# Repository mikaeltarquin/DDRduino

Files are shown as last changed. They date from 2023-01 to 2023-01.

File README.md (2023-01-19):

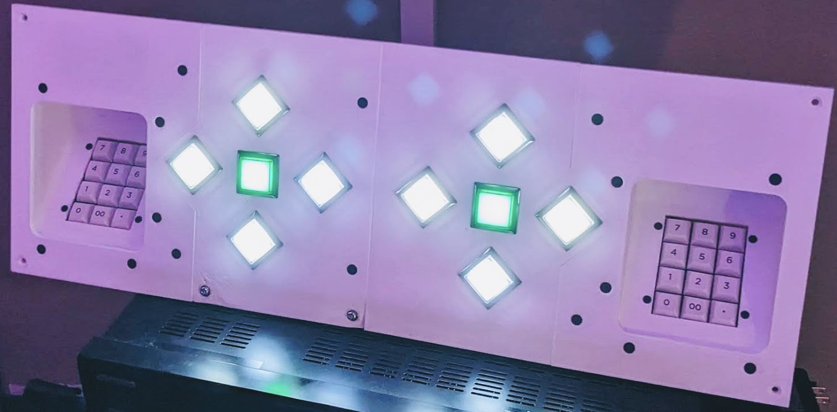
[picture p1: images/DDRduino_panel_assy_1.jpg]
DDRduino Control Panel Build

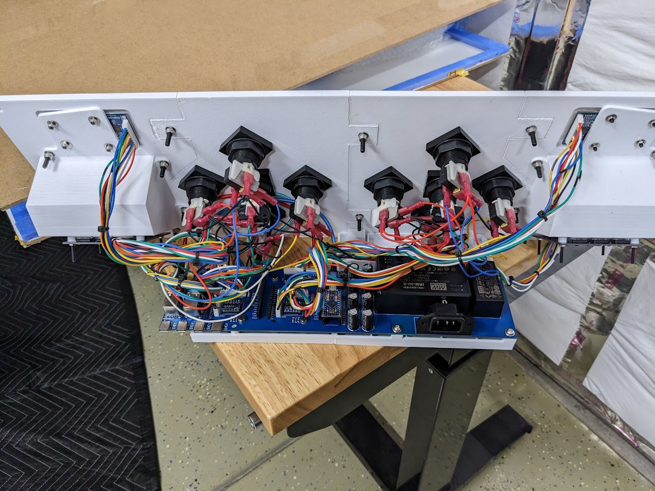
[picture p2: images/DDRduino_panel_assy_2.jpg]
DDRduino Control Panel wiring gore


# DDRduino
Custom PCB for handling DDR control panel, keypad, card reader, and LED controls.
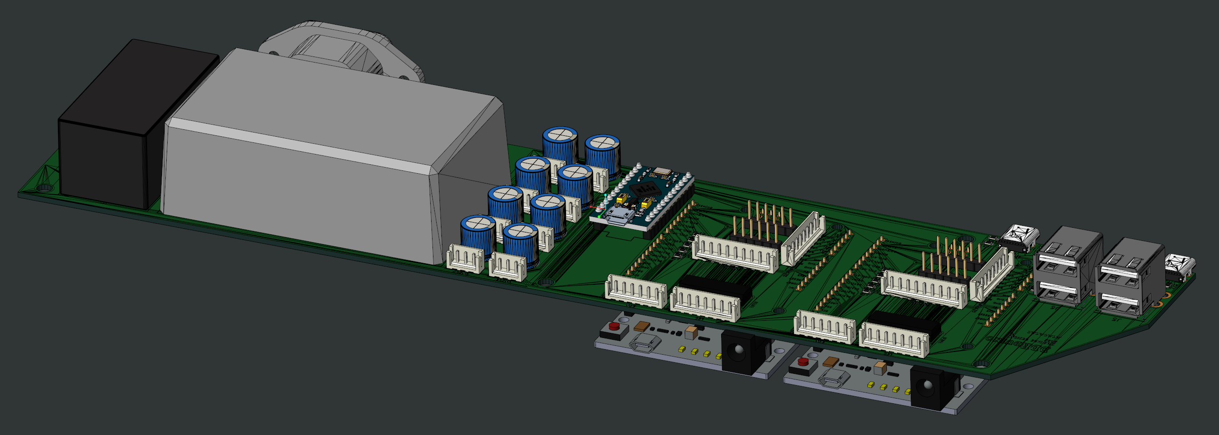
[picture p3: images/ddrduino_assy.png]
DDRduino Assembly


# Keymani
A side project for DDRduino, but theoretically compatible with regular setups as well! This is a 12 button matrix numpad, and connects to the rest of the system with an 8 pin JST connector.
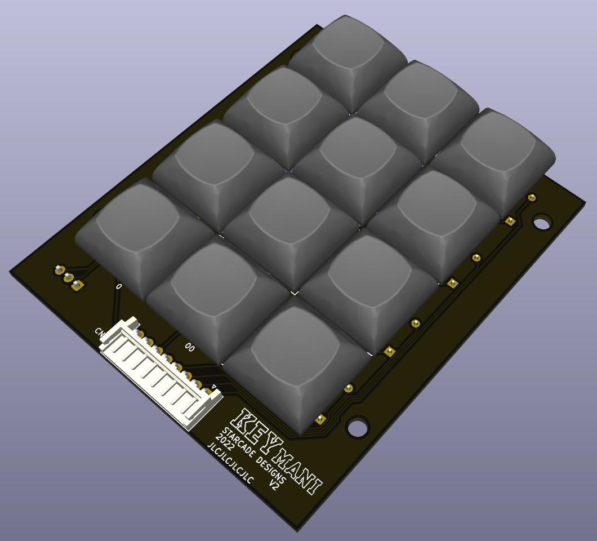
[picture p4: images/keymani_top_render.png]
Keymani PCB


# Acknowledgements
[PN5180-cardio Navigation LPCD](https://github.com/CrazyRedMachine/PN5180-cardio/tree/navigation-lpcd) by CrazyRedMachine 

[WS2812B Addressable LED Arduino Code](https://github.com/Moldypie/hid-lights-with-individually-addressable-strips-and-a-keypad) by Moldypie

# Parts List
## Top Level Components

| Component | Description |
| --- | --- |
| DDRduino Assembly | Integrated board combining microcontrollers, USB interfaces, JST connector headers for Buttons/LEDs/card reader/keypad, and lighting power supplies. |
| Keymani Assembly | A 12-key matrix numpad for entering your PIN. |
| 8x IST 406 White<br><br>2x IST 406 Green | IST-406 White buttons for the direction buttons.<br><br>2x IST-406 Green buttons for the Start buttons.<br><br>[IST MALL link](https://www.istmall.co.kr/us/goods/goods_view.php?goodsNo=1009992263) | 
| 2x PN5180 | NFC card readers to read your IC cards.<br><br>[AliExpress link](https://www.aliexpress.com/w/wholesale-pn5180.html) |
| Control Panel | Up to you! I designed a very janky panel that I've been printing in pieces, you can do better! |

## DDRduino Components

| Component ID | Component | Description |Quantity |
| --- | --- | --- | --- |
| U1 | 703W-00/54 | AC Power Entry Module | 1 |
| U101, U201 | TBD62003APG | Transistor Array | 2 |
| U301 | Arduino ProMicro | microcontroller for cab LEDs | 1 |
| <> | Arduino Leonardo | microcontroller for controls/button LEDs/card reader/keypad | 2 |
| <> | BOB-12009 | SparkFun Logic Level Converter - Bi-Directional | 2 |
| PS1 | IRM-60-5 PSU | power supply for cab LEDs | 1 |
| PS2 | IRM-20-12 PSU | power supply for button LEDs | 1 |
| C301-C308 | 1000 uF D10.0mm | Radial electrolytic capacitors (I used 25V) | 8 |
| R1-R4, R13-R14 | 1 MOhm 0805 | SMD resistors | 6 |
| R5-R12 | 5.11 kOhm 0805 | SMD resistors | 8 |
| R101-R105, R201-R205 | 10 kOhm 0805 | SMD resistors | 10 |
| R301-R308 | 330 Ohm 0805 | SMD resistors | 8 |
| J5-J6 | USB1035-GF-P-0-B-B	| USB-A ports | 2 |
| J1-J4 | USB4085-GF-A | USB-C ports | 4 |
| CN101, CN201 | JST_EH_B6B-EH-A_1x06_P2.50mm_Vertical	| 6 pin connector header for buttons | 2 |
| CN102, CN202 | JST_EH_B7B-EH-A_1x07_P2.50mm_Vertical	| 7 pin connector header for button LEDs | 2 |
| CN104, CN204 | JST_EH_B11B-EH-A_1x11_P2.50mm_Vertical	| 11 pin connector header for PN5180 card reader | 2 |
| CN105, CN205 | JST_EH_B8B-EH-A_1x08_P2.50mm_Vertical	| 8 pin connector header for keypad | 2 |
| CN301-CN308 | JST_EH_B3B-EH-A_1x03_P2.50mm_Vertical	| 3 pin connector header for cab LEDs | 8 |
| CN111-CN112, CN211-CN212, J101, J201 | PinHeader_1x06_P2.54mm_Vertical	| 6 pin header for logic level converter, Leonardo | 6 |
| J102-J103, J202-J203 | PinHeader_1x08_P2.54mm_Vertical	| 8 pin header for Leonardo | 4 |
| J104, J204 | PinHeader_1x10_P2.54mm_Vertical	| 10 pin header for Leonardo | 2 |
| J105, J205 | PinSocket_2x03_P2.54mm_Vertical	| 3 pin socket for Leonardo | 2 |

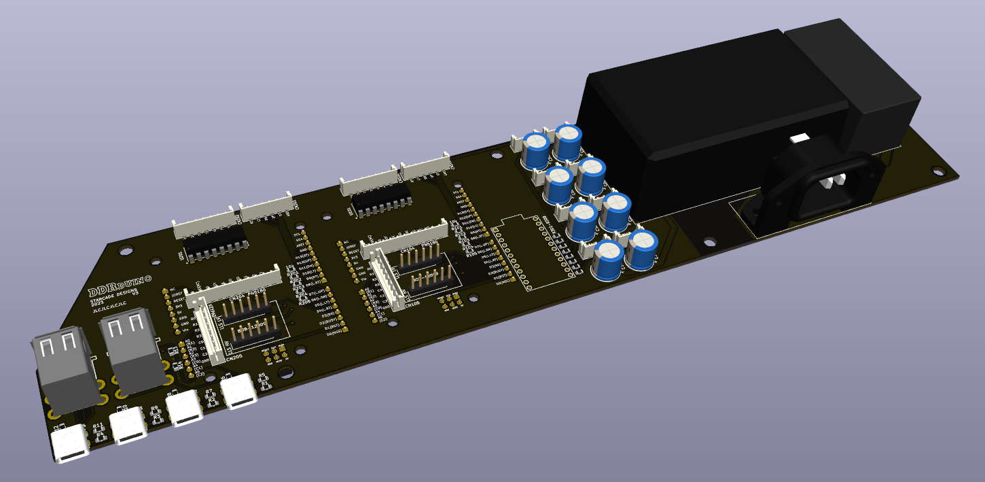
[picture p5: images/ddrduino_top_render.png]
DDRduino PCB


## Keymani Components

| Component ID | Component | Description |Quantity |
| --- | --- | --- | --- |
| SW1-SW12 | PG1353 | Kailh Choc V2 keyboard switch | 12 |
| D1-D12 | 1N4148| D_DO-35_SOD27_P7.62mm_Horizontal	diodes for matrix keypad | 12 |
| CN1 | JST_EH_S8B-EH_1x08_P2.50mm_Horizontal	| 8 pin connector header for external connection (DDRduino) | 1 |
| <> | Keycaps! | I used 2x ["DSA PBT Blue and White Keycaps Set 145 Keys"](https://www.aliexpress.us/item/3256802412526867.html) keycap sets I found on sale at KBDfans, but it seems to be out of stock/discontinued. The main thing for me was finding a set with a 00 key. | 2 |

There are also provisions for LEDs, but I don't use them since they interfere with my switches and are blocked by my keycaps:
| Component ID | Component | Description |Quantity |
| --- | --- | --- | --- |
| C1-C12 | 100 nF 0805 | SMD capacitors | 12 |
| D13-D24 | LED_SK6812MINI_PLCC4_3.5x3.5mm_P1.75mm | SK6812MINI LEDs | 12 |
| CN2 | JST_EH_B3B-EH-A_1x03_P2.50mm_Vertical | 3 pin connector header for LED control | 1 |

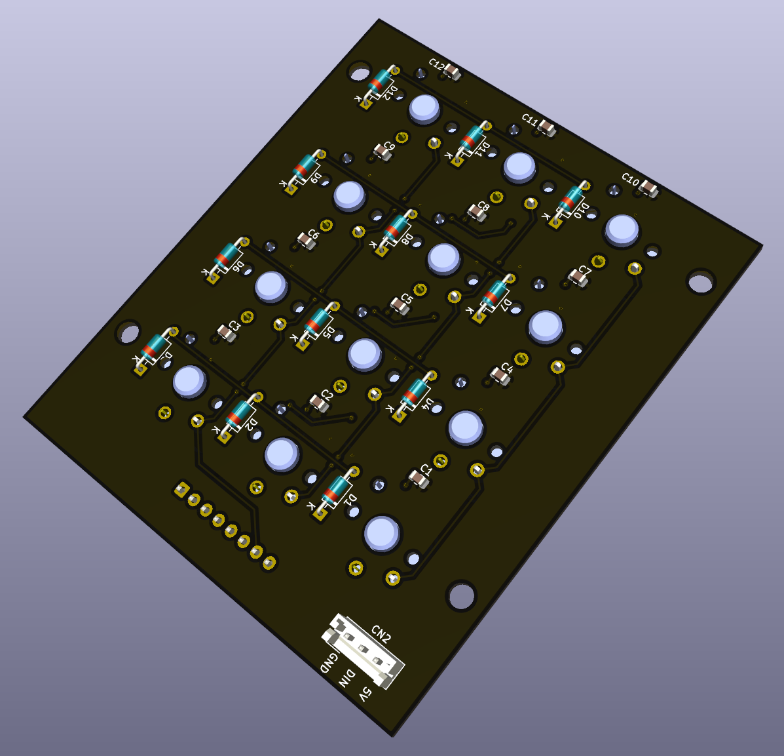
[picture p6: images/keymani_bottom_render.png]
Keymani PCB


# Arduino Setup
1. Download the [Navigation LPCD branch](https://github.com/CrazyRedMachine/PN5180-cardio/tree/navigation-lpcd) of CrazyRedMachine's PN5180-cardio code.
2. Replace the `Config.h ` with the custom `Config.h.PN5180-cardio-navigation-lpcd (1P)` or `Config.h.PN5180-cardio-navigation-lpcd (2P)` versions, depending on which player control Arduino you are flashing. 
3. Upload the sketches to the Arduino Leonardos.
4. If using the LED controller, upload the `LED_promicro_version.ino` sketch to your ProMicro.

## PN5180-cardio Config Changes:
```
#define PN5180_PIN_NSS  0
#define PN5180_PIN_BUSY 2
#define PN5180_PIN_RST  1
#define PIN_ROW1 3
#define PIN_ROW2 A0
#define PIN_ROW3 A1
#define PIN_ROW4 A2
#define PIN_COL1 A3
#define PIN_COL2 A4
#define PIN_COL3 A5
#define PIN_BUT_UP    12
#define PIN_BUT_DOWN  11
#define PIN_BUT_LEFT  10
#define PIN_BUT_RIGHT 9
#define PIN_BUT_START 13  
#define PIN_LED_UP    7
#define PIN_LED_DOWN  6
#define PIN_LED_LEFT  5
#define PIN_LED_RIGHT 4
#define PIN_LED_START 8
```
In additon, player 2 changes:
```
#define CARDIO_ID 2
#define CUSTOM_VIDPID 2
```

## LED Code Changes:
```
#define LED_PIN_1     10
#define LED_PIN_2     16
#define LED_PIN_3     14
#define LED_PIN_4     15
#define LED_PIN_5     18
#define LED_PIN_6     19
#define LED_PIN_7     20
#define LED_PIN_8     21
#define NUM_STRIPS 8
```

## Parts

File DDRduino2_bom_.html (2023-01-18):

Source File | DDRduino2.kicad_sch
BoM Date | 2022/12/28 22:12:46
Schematic Version
Schematic Date
PCB Variant | default
KiCad Version | Eeschema (6.0.1)
Component Groups | 26
Component Count (per PCB) | 82
Fitted Components (per PCB) | 82
Number of PCBs | 1
Total Component Count (for 1 PCBs) | 82
 | Description | Part | References | Value | Footprint | Quantity Per PCB | Datasheet | Function | MANUFACTURER | MAXIMUM_PACKAGE_HEIGHT | PARTREV | STANDARD
1 | Unpolarized capacitor | C | C301 C302 C303 C304 C305 C306 C307 C308 | 1000uF | CP_Radial_D10.0mm_P5.00mm | 8 | ~
2 | Generic connector, single row, 01x03, script generated (kicad-library-utils/schlib/autogen/connector/) | Conn_01x03 | CN301 CN302 CN303 CN304 CN305 CN306 CN307 CN308 | Conn_01x03 | JST_EH_B3B-EH-A_1x03_P2.50mm_Vertical | 8 | ~ | LED_P1_F LED_P1_W LED_P2_F LED_P2_W
3 | Generic connector, single row, 01x06, script generated (kicad-library-utils/schlib/autogen/connector/) | Conn_01x06_Female | CN101 CN201 | Conn_01x06_Female | JST_EH_B6B-EH-A_1x06_P2.50mm_Vertical | 2 | ~ | BTN
4 | Generic connector, single row, 01x07, script generated (kicad-library-utils/schlib/autogen/connector/) | Conn_01x07_Female_1 | CN102 CN202 | Conn_01x07_Female | JST_EH_B7B-EH-A_1x07_P2.50mm_Vertical | 2 | ~ | LED
5 | Generic connector, single row, 01x08, script generated (kicad-library-utils/schlib/autogen/connector/) | Conn_01x08_Female | CN105 CN205 | Conn_01x08_Female | JST_EH_B8B-EH-A_1x08_P2.50mm_Vertical | 2 | ~ | KEYPAD
6 | Generic connector, single row, 01x11, script generated (kicad-library-utils/schlib/autogen/connector/) | Conn_01x11_Female | CN104 CN204 | Conn_01x11_Female | JST_EH_B11B-EH-A_1x11_P2.50mm_Vertical | 2 | ~ | PN5180
7 | Generic connector, single row, 01x06, script generated (kicad-library-utils/schlib/autogen/connector/) | Conn_01x06_Male_1 | CN111 CN211 | LLS HV | PinHeader_1x06_P2.54mm_Vertical | 2 | ~
8 | Generic connector, single row, 01x06, script generated (kicad-library-utils/schlib/autogen/connector/) | Conn_01x06_Male | CN112 CN212 | LLS LV | PinHeader_1x06_P2.54mm_Vertical | 2 | ~
9 | Generic connector, single row, 01x06, script generated (kicad-library-utils/schlib/autogen/connector/) | Conn_01x06 | J101 J201 | Conn_01x06 | PinHeader_1x06_P2.54mm_Vertical | 2 | ~ | LEO HEADER 1
10 | Generic connector, single row, 01x08, script generated (kicad-library-utils/schlib/autogen/connector/) | Conn_01x08 | J102 | Conn_01x08 | PinHeader_1x08_P2.54mm_Vertical | 1 | ~ | LEO HEADER 2
11 | Generic connector, single row, 01x08, script generated (kicad-library-utils/schlib/autogen/connector/) | Conn_01x08_1 | J103 J203 | Conn_01x08 | PinHeader_1x08_P2.54mm_Vertical | 2 | ~ | LEO HEADER 3
12 | Generic connector, single row, 01x08, script generated (kicad-library-utils/schlib/autogen/connector/) | Conn_01x08_2 | J202 | Conn_01x08 | PinHeader_1x08_P2.54mm_Vertical | 1 | ~ | LEO HEADER 2
13 | Generic connector, single row, 01x10, script generated (kicad-library-utils/schlib/autogen/connector/) | Conn_01x10 | J104 J204 | Conn_01x10 | PinHeader_1x10_P2.54mm_Vertical | 2 | ~ | LEO HEADER 4
14 | Generic connector, double row, 02x03, odd/even pin numbering scheme (row 1 odd numbers, row 2 even numbers), script generated (kicad-library-utils/schlib/autogen/connector/) | Conn_02x03_Odd_Even | J105 J205 | Conn_02x03 | PinSocket_2x03_P2.54mm_Vertical | 2 | ~ | LEO HEADER 5
15 |  | USB1035-XX-X-X-X-B_REVE_1 | J5 | USB1035-GF-P-0-B-B_REVE | GCT_USB1035-XX-X-X-X-B_REVE | 1 | ~ |  | GCT
16 |  | USB1035-XX-X-X-X-B_REVE | J6 | USB1035-GF-P-0-B-B_REVE | GCT_USB1035-XX-X-X-X-B_REVE | 1 | ~ |  | GCT
17 |  | USB4085-GF-A_REVA4 | J1 J2 J3 J4 | USB4085-GF-A_REVA4 | GCT_USB4085-GF-A_REVA4 | 4 | https://www.usb.org/sites/default/files/documents/usb_type-c.zip |  | Global Connector Technology | 3.46mm | A4 | Manufacturer Recommendations
18 | 12V, 1.8A, 21.6W, Isolated, AC-DC, 219A(IRM20) | IRM-20-12 | PS2 | IRM-20-12 | Converter_ACDC_MeanWell_IRM-20-xx_THT | 1 | http://www.meanwell.com/Upload/PDF/IRM-20/IRM-20-SPEC.PDF
19 | 5V, 10A, 50W, Isolated, AC-DC, IRM60 | IRM-60-5 | PS1 | IRM-60-5 | Converter_ACDC_MeanWell_IRM-60-xx_THT | 1 | http://www.meanwellusa.com/productPdf.aspx?i=687
20 | Resistor | R | R301 R302 R303 R304 R305 R306 R307 R308 | 330 | R_0805_2012Metric | 8 | ~
21 | Resistor | R | R5 R6 R7 R8 R9 R10 R11 R12 | 5.11K | R_0805_2012Metric_Pad1.20x1.40mm_HandSolder | 8 | ~
22 | Resistor | R | R101 R102 R103 R104 R105 R201 R202 R203 R204 R205 | 10k | R_0805_2012Metric | 10 | ~
23 | Resistor | R | R1 R2 R3 R4 R13 R14 | 1M | R_0805_2012Metric_Pad1.20x1.40mm_HandSolder | 6 | ~
24 |  | 703W-00{slash}54 | U1 | 703W-00/54 | 703W-00_54 | 1
25 |  | ProMicro | U301 | ProMicro | ProMicro | 1
26 |  | TBD62003APG | U101 U201 | TBD62003APG | TBD62003APG | 2

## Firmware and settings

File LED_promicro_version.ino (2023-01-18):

#include <Joystick.h>

#include "PluggableUSB.h"
#include "HID.h"

#include <FastLED.h>
//#include <Keyboard.h>
#include <EEPROM.h>
//#include <Keypad.h>

//#include <Adafruit_PWMServoDriver.h>

// LED Strip Setup
#define LED_PIN_1     10
#define LED_PIN_2     16
#define LED_PIN_3     14
#define LED_PIN_4     15
#define LED_PIN_5     18
#define LED_PIN_6     19
#define LED_PIN_7     20
#define LED_PIN_8     21
#define NUM_LEDS    56
#define NUM_STRIPS 8
CRGB leds[NUM_STRIPS][NUM_LEDS];

// HID lighting setup
typedef struct {
  uint8_t brightness;
} SingleLED;

typedef struct {
  uint8_t r;
  uint8_t g;
  uint8_t b;
} RGBLed;

//const byte ROWS = 4;
//const byte COLS = 3;
//  /* This is to use the toprow keys */
//char numpad[ROWS][COLS] = {
// {'0', 'o', 'p'},
// {'1', '2', '3'},
// {'4', '5', '6'},
// {'7', '8', '9'}//0,1247
//};
//byte rowPins[ROWS] = { 1, 6, 5, 3 }; //connect to the row pinouts of the keypad
//byte colPins[COLS] = { 2, 0, 4 }; //connect to the column pinouts of the keypad
//Keypad kpd = Keypad(makeKeymap(numpad), rowPins, colPins, ROWS, COLS);

// The single LEDs will be first in BTools
// The RGB LEDs will come afterwards, with R/G/B individually
#define NUMBER_OF_SINGLE 0
#define NUMBER_OF_RGB 8
boolean updateLights = false;

void setup() {
  FastLED.addLeds<WS2812B, LED_PIN_1, GRB>(leds[0], NUM_LEDS);
  FastLED.addLeds<WS2812B, LED_PIN_2, GRB>(leds[1], NUM_LEDS);
  FastLED.addLeds<WS2812B, LED_PIN_3, GRB>(leds[2], NUM_LEDS);
  FastLED.addLeds<WS2812B, LED_PIN_4, GRB>(leds[3], NUM_LEDS);
  FastLED.addLeds<WS2812B, LED_PIN_5, GRB>(leds[4], NUM_LEDS);
  FastLED.addLeds<WS2812B, LED_PIN_6, GRB>(leds[5], NUM_LEDS);
  FastLED.addLeds<WS2812B, LED_PIN_7, GRB>(leds[6], NUM_LEDS);
  FastLED.addLeds<WS2812B, LED_PIN_8, GRB>(leds[7], NUM_LEDS);
  FastLED.setBrightness(120);

//  kpd.setDebounceTime(10);
//  Keyboard.begin();
}

//void keypadCheck(){
//  if (kpd.getKeys())
//  {
//    for (int i = 0; i < LIST_MAX; i++) // Scan the whole key list.
//    {
//      if ( kpd.key[i].stateChanged )   // Only find keys that have changed state.
//      {
//        switch (kpd.key[i].kstate) {  // Report active key state : IDLE, PRESSED, HOLD, or RELEASED
//          case PRESSED:
//            Keyboard.press(kpd.key[i].kchar);
//            break;
//          case HOLD:
//            break;
//          case RELEASED:
//            Keyboard.release(kpd.key[i].kchar);
//      }
//    }
//  }
//}
//}

void loop() {
//  keypadCheck();

  // hid Lighting
  if (updateLights){
    FastLED.show();
    updateLights = false;
  }
}

void light_update(SingleLED* single_leds, RGBLed* rgb_leds) {
  for(int i = 0; i < NUMBER_OF_RGB; i++) {
    CRGB color = CRGB(rgb_leds[i].r, rgb_leds[i].g, rgb_leds[i].b);
    for (int j = 0; j < NUM_LEDS; j++) {
      leds[i][j] = color;
    }
  }

  updateLights = true;

  //0-22, 23-45, 46-68, 69-91, 92-114
  //0,     1,    2,     3,     4
  //title, left, front, right, top
  //2,     0,     4,   1,    3
  //front, title, top, left, right
}


// ******************************
// don't need to edit below here

#define NUMBER_OF_LIGHTS (NUMBER_OF_SINGLE + NUMBER_OF_RGB*3)
#if NUMBER_OF_LIGHTS > 63
  #error You must have less than 64 lights
#endif

union {
  struct {
    SingleLED singles[NUMBER_OF_SINGLE];
    RGBLed rgb[NUMBER_OF_RGB];
  } leds;
  uint8_t raw[NUMBER_OF_LIGHTS];
} led_data;

static const uint8_t PROGMEM _hidReportLEDs[] = {
    0x05, 0x01,                    // USAGE_PAGE (Generic Desktop)
    0x09, 0x00,                    // USAGE (Undefined)
    0xa1, 0x01,                    // COLLECTION (Application)
    // Globals
    0x95, NUMBER_OF_LIGHTS,        //   REPORT_COUNT
    0x75, 0x08,                    //   REPORT_SIZE (8)
    0x15, 0x00,                    //   LOGICAL_MINIMUM (0)
    0x26, 0xff, 0x00,//0x00, 0x00, 0x50,              //   LOGICAL_MAXIMUM (255)0x26, 0xff, 0x00
    0x05, 0x0a,                    //   USAGE_PAGE (Ordinals)
    // Locals
    0x19, 0x01,                    //   USAGE_MINIMUM (Instance 1)
    0x29, NUMBER_OF_LIGHTS,        //   USAGE_MAXIMUM (Instance n)
    0x91, 0x02,                    //   OUTPUT (Data,Var,Abs)
    // BTools needs at least 1 input to work properly
    0x19, 0x01,                    //   USAGE_MINIMUM (Instance 1)
    0x29, 0x01,                    //   USAGE_MAXIMUM (Instance 1)
    0x81, 0x03,                    //   INPUT (Cnst,Var,Abs)
    0xc0                           // END_COLLECTION
};

// This is almost entirely copied from NicoHood's wonderful RawHID example
// Trimmed to the bare minimum
// https://github.com/NicoHood/HID/blob/master/src/SingleReport/RawHID.cpp
class HIDLED_ : public PluggableUSBModule {

  uint8_t epType[1];
  
  public:
    HIDLED_(void) : PluggableUSBModule(1, 1, epType) {
      epType[0] = EP_TYPE_INTERRUPT_IN;
      PluggableUSB().plug(this);
    }

    int getInterface(uint8_t* interfaceCount) {
      *interfaceCount += 1; // uses 1
      HIDDescriptor hidInterface = {
        D_INTERFACE(pluggedInterface, 1, USB_DEVICE_CLASS_HUMAN_INTERFACE, HID_SUBCLASS_NONE, HID_PROTOCOL_NONE),
        D_HIDREPORT(sizeof(_hidReportLEDs)),
        D_ENDPOINT(USB_ENDPOINT_IN(pluggedEndpoint), USB_ENDPOINT_TYPE_INTERRUPT, USB_EP_SIZE, 16)
      };
      return USB_SendControl(0, &hidInterface, sizeof(hidInterface));
    }
    
    int getDescriptor(USBSetup& setup)
    {
      // Check if this is a HID Class Descriptor request
      if (setup.bmRequestType != REQUEST_DEVICETOHOST_STANDARD_INTERFACE) { return 0; }
      if (setup.wValueH != HID_REPORT_DESCRIPTOR_TYPE) { return 0; }
    
      // In a HID Class Descriptor wIndex contains the interface number
      if (setup.wIndex != pluggedInterface) { return 0; }
    
      return USB_SendControl(TRANSFER_PGM, _hidReportLEDs, sizeof(_hidReportLEDs));
    }
    
    bool setup(USBSetup& setup)
    {
      if (pluggedInterface != setup.wIndex) {
        return false;
      }
    
      uint8_t request = setup.bRequest;
      uint8_t requestType = setup.bmRequestType;
    
      if (requestType == REQUEST_DEVICETOHOST_CLASS_INTERFACE)
      {
        return true;
      }
    
      if (requestType == REQUEST_HOSTTODEVICE_CLASS_INTERFACE) {
        if (request == HID_SET_REPORT) {
          if(setup.wValueH == HID_REPORT_TYPE_OUTPUT && setup.wLength == NUMBER_OF_LIGHTS){
            USB_RecvControl(led_data.raw, NUMBER_OF_LIGHTS);
            light_update(led_data.leds.singles, led_data.leds.rgb);
            return true;
          }
        }
      }
    
      return false;
    }
};

HIDLED_ HIDLeds;

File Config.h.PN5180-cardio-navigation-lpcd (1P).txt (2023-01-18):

#ifndef CONFIG_h
#define CONFIG_h

/* PN5180 support (disable to test only the navigation buttons/keypad) */
#define WITH_PN5180 1

/* ISO14443 support (for older Aime/Nesica/BANAPASSPORT cards... reader will pretend it was a FeliCa for maximum cardio compatibility) */
#define WITH_ISO14443 1

/* Pinout for the PN5180 free pins */
#define PN5180_PIN_NSS  0
#define PN5180_PIN_BUSY 2
#define PN5180_PIN_RST  1
#define PN5180_PIN_IRQ  30 //additional gpio

/* Use a matrix keypad */
#define WITH_KEYPAD 1
  #define PIN_ROW1 3
  #define PIN_ROW2 A0
  #define PIN_ROW3 A1
  #define PIN_ROW4 A2
  #define PIN_COL1 A3
  #define PIN_COL2 A4
  #define PIN_COL3 A5

/* Player ID (1 or 2) */
#define CARDIO_ID 1
/* Enable custom VID/PID (will require to hold reset button to reflash firmware) */
#define CUSTOM_VIDPID 1

/* NAVIGATION */
#define WITH_NAVIGATION 1
  #define PIN_BUT_UP    12
  #define PIN_BUT_DOWN  11
  #define PIN_BUT_LEFT  10
  #define PIN_BUT_RIGHT 9
  #define PIN_BUT_START 13  
  #define PIN_LED_UP    7
  #define PIN_LED_DOWN  6
  #define PIN_LED_LEFT  5
  #define PIN_LED_RIGHT 4
  #define PIN_LED_START 8

#endif /* CONFIG_H */
